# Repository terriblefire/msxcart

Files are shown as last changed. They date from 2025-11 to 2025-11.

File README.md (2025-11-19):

# MSX Cartridge - Simple CPLD-Based MegaROM Mapper

A minimalist MSX cartridge design based on the Xilinx XC9536XL CPLD, implementing a standard MegaROM mapper for bank-switched ROM cartridges.




---

## Discord

https://discord.gg/aXGkKWJQ

## ⚠️ Project Status - SUPERSEDED

**This project has been superseded by the RISKYMSX project** ([arkadiuszmakarenko/RISKYMSX](https://github.com/arkadiuszmakarenko/RISKYMSX)).

### 🎯 **We recommend building RISKYMSX instead**

RISKYMSX is a modern, feature-rich MSX cartridge solution that offers significant advantages over this simple CPLD design:

### Why Choose RISKYMSX

| Feature | RISKYMSX (Recommended) | MSX Cartridge (This Project) |
|---|---|---|
| **ROM Loading** | USB pen drive, hot-swappable | Requires ROM programmer |
| **ROM Capacity** | Up to 256KB | Up to 256KB |
| **SCC Support** | Software SCC emulation | None |
| **Convenience** | Change ROMs instantly via USB | Must reprogram ROM chip |
| **Modern MCU** | RISC-V CH32V303 | Legacy CPLD |
| **Firmware Updates** | USB or WCH-LinkE | JTAG programmer |
| **Mapper Support** | Konami, ASCII 8K/16K, Neo, SCC | Konami, ASCII 8K/16K |
| **User Experience** | Plug and play with USB drive | Requires hardware tools |

**👉 For new builds, please use [RISKYMSX](https://github.com/arkadiuszmakarenko/RISKYMSX)** - it provides better functionality, easier ROM management, and a superior user experience.

### About This Archive

This repository remains available for:
- Historical reference
- Educational purposes (learning CPLD design)
- Users who already built this hardware
- Those who need the absolute simplest possible design

However, for any new MSX cartridge project, RISKYMSX is the superior choice.

---

## Features

- **Xilinx XC9536XL CPLD** - Small, reliable, low-cost programmable logic
- **Standard MegaROM Mapper** - 4 switchable ROM pages (8KB each)
- **MSX Compatible** - Works with all MSX computers
- **Simple Design** - Minimal component count, easy to build
- **Open Source** - GPL v3 licensed hardware and HDL
- **Automated Build System** - Docker-based builds for firmware and PCB manufacturing files

## Hardware Specifications

- **Target Device**: Xilinx XC9536XL-10-VQ44 CPLD
- **Interface**: MSX cartridge slot (Z80 bus compatible)
- **Memory Mapping**: 4 page registers for bank switching
- **ROM Size**: Supports up to 512KB (limited by CPLD I/O)
- **Power**: 5V from MSX cartridge slot

## Memory Map

The mapper implements standard MSX MegaROM banking:

| Address Range | Page | Function |
|---|---|---|
| `0x4000-0x5FFF` | 0 | Fixed to bank 0 |
| `0x6000-0x7FFF` | 1 | Switchable (register 1) |
| `0x8000-0x9FFF` | 2 | Switchable (register 2) |
| `0xA000-0xBFFF` | 3 | Switchable (register 3) |

Bank switching is performed by writing to specific memory addresses during M1 cycle.

## Building

### Prerequisites

- Docker (for building firmware and PCB files)
- Git (for version control)
- Make (for build automation)

### Build Firmware

```bash
# Build CPLD firmware
make -C boards

# Output: boards/msxcart_YYYY_MM_DD_GITHASH.zip
```

### Generate PCB Manufacturing Files

```bash
# Generate Gerber files
make -C eagle gerbers

# Generate BOM and CPL for assembly
make -C eagle assembly

# Generate PDF schematic
make -C eagle pdf
```

## Manufacturing

### PCB Fabrication

1. Use the Gerber ZIP from `eagle/tfcart_*.zip` to order PCBs from your preferred manufacturer (JLCPCB, PCBWay, etc.)
2. The design is a 4-layer board optimized for standard PCB processes

### PCB Assembly

1. Use `eagle/tfcart_bom.csv` (Bill of Materials) for component ordering
2. Use `eagle/tfcart_cpl.csv` (Component Placement List) if using assembly services
3. Alternatively, hand-solder components - the board is designed for easy assembly

### Programming the CPLD

1. Connect a JTAG programmer to the CPLD
2. Flash the `.jed` file from `boards/msxcartr1/msxcartr1_top.jed`
3. Use Xilinx iMPACT or xc3sprog for programming

### Programming the ROM

1. Program your ROM chip with the desired MSX ROM image
2. Install the ROM chip in the socket
3. Insert into MSX cartridge slot

## Project Structure

```
msxcart/
├── rtl/                    # Verilog HDL source files
│   ├── msxcart_top.v      # Top-level module
│   └── mapper.v           # Memory mapper logic
├── boards/                 # CPLD build configuration
│   ├── msxcartr1/         # Revision 1 board files
│   │   ├── Makefile       # Board-specific build
│   │   └── msxcartr1.ucf  # Pin constraints
│   ├── Makefile           # Top-level build
│   ├── Makefile.inc       # Docker environment
│   └── Makefile.cpld      # Xilinx ISE flow
├── eagle/                  # PCB design files
│   ├── tfcart.brd         # Eagle board file
│   ├── tfcart.sch         # Eagle schematic
│   ├── Makefile           # PCB build automation
│   ├── extract_bom.py     # BOM extraction script
│   └── extract_cpl.py     # CPL extraction script
└── .github/workflows/      # CI/CD automation
    ├── actions.yml         # Firmware build
    ├── gerbers.yml         # Gerber generation
    ├── generate_assembly.yml # BOM/CPL generation
    ├── schematic-pdf.yml   # PDF schematic
    └── release.yml         # Release packaging
```

## Development

### Build System

The project uses Docker containers for reproducible builds:

- `terriblefire78/xilinx:v1` - Xilinx ISE 10.1 for CPLD synthesis
- `terriblefire78/eagle:v1` - Eagle CAM for Gerber generation
- `terriblefire78/eagle-pdf` - PDF schematic generation

### Modifying the Design

1. Edit Verilog files in `rtl/`
2. Adjust pin assignments in `boards/msxcartr1/msxcartr1.ucf`
3. Build and test: `make -C boards`
4. The build system automatically handles Docker environment

### Testing

Flash the generated `.jed` file to your CPLD and test with an MSX computer. The mapper should properly switch ROM banks when games access the appropriate memory addresses.

## GitHub Actions

The repository includes automated workflows:

- **Firmware Build** - Builds CPLD firmware on code changes
- **Gerber Generation** - Creates PCB manufacturing files
- **Assembly Files** - Generates BOM and CPL
- **Schematic PDF** - Produces documentation
- **Release Packaging** - Creates complete release bundles

Releases are automatically created when you push a git tag:

```bash
git tag -a v1.0 -m "Release version 1.0"
git push origin v1.0
```

## License

This project is licensed under the GNU General Public License v3.0 - see the [LICENSE](LICENSE) file for details.

Copyright (C) 2021-2025 Stephen J. Leary

## Acknowledgments

- Original design concept by Stephen J. Leary
- Inspired by the MSX community's dedication to preserving retro computing

## Related Projects

- **[RISKYMSX](https://github.com/arkadiuszmakarenko/RISKYMSX)** - Feature-rich USB-programmable MSX cartridge with SCC emulation

## Contributing

Contributions are welcome! Please feel free to submit pull requests or open issues for bugs and feature requests.

## Support

For questions, issues, or discussions:

1. Open an issue on GitHub
2. Check existing issues for solutions
3. Review the MSX community forums for related discussions

---

**Note**: This is a hardware project. Users must have appropriate skills for PCB assembly and CPLD programming. This design is provided as-is for educational and hobbyist purposes.

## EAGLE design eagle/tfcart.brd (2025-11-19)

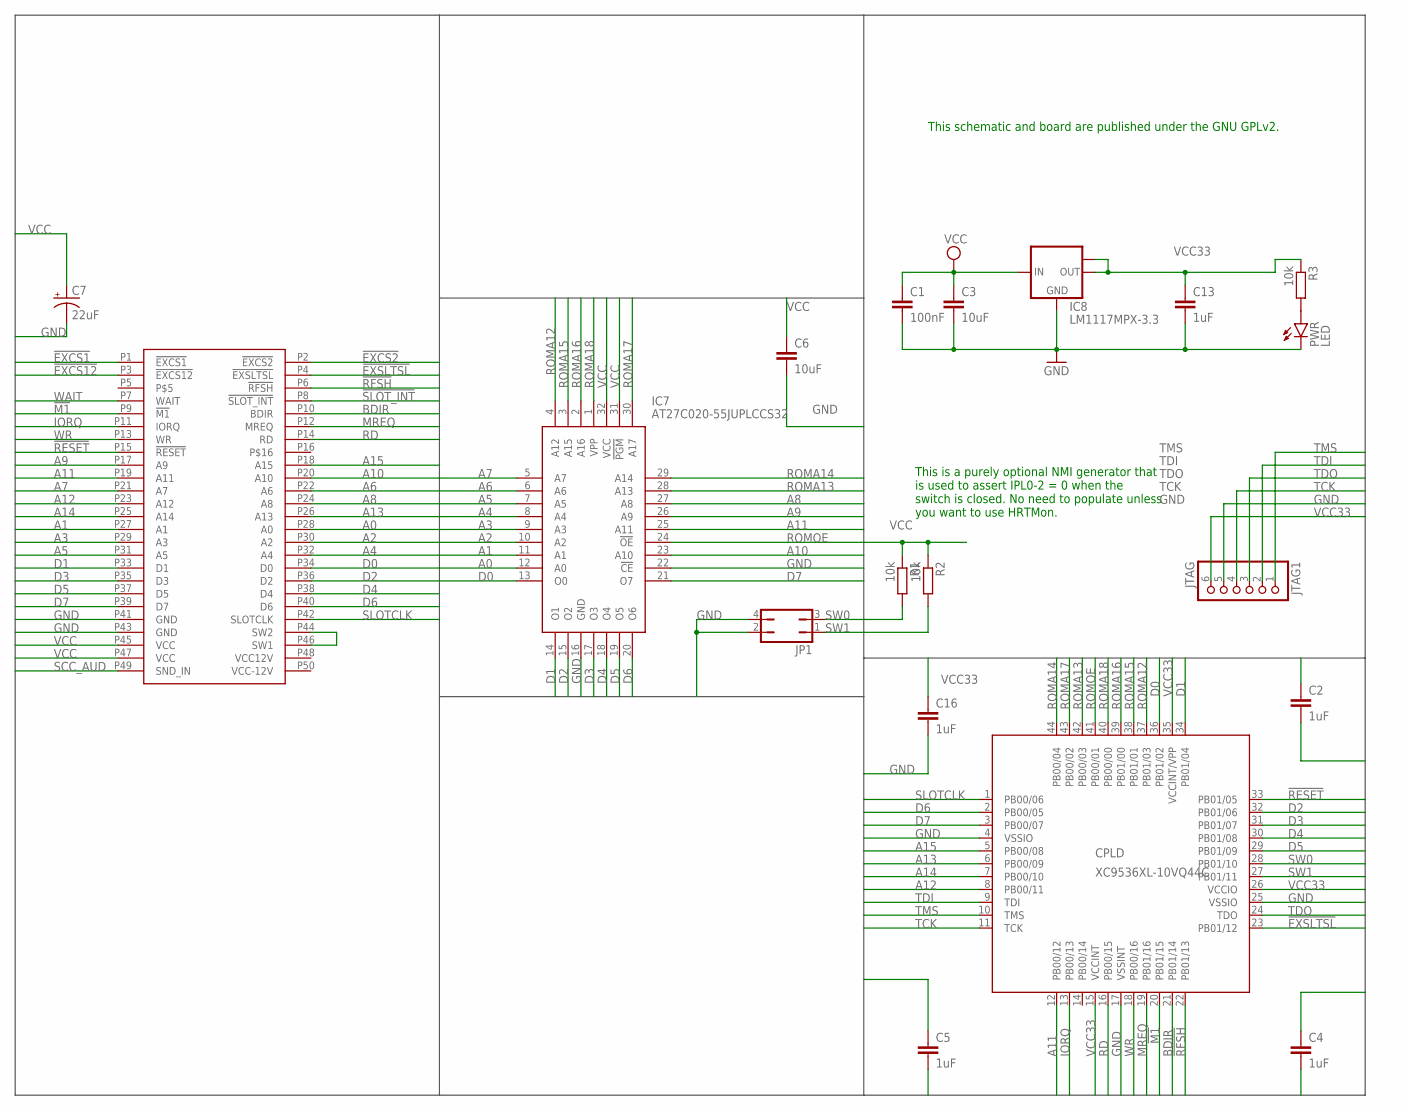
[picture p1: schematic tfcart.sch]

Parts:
C1: 100nF; C1206
C2, C4, C5, C16: 1uF; C0603
C3, C6: 10uF; C0603
C7: 22uF; PANASONIC_B
C13: 1uF; C1206
CN1: MSX_CART
CPLD: XC9536XL-10VQ44C; SQFP-S-10X10-44
IC7: AT27C020-55JUPLCCS32; PLCC-S32
IC8: LM1117MPX-3.3; SOT223
JP1: JP2Q
JTAG1: JTAG; 1X06_ROUND
PWR: LED; SML0805
R1, R2, R3: 10k; R0603

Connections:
!EXCS1: CN1.P1 (!EXCS1)
!EXCS2: CN1.P2 (!EXCS2)
!EXCS12: CN1.P3 (!EXCS12)
!EXSLTSL: CN1.P4 (!EXSLTSL), CPLD.23 (PB01/12)
!M1: CN1.P9 (!M1), CPLD.20 (PB01/15)
!RESET: CN1.P15 (!RESET), CPLD.33 (PB01/05)
!RFSH: CN1.P6 (!RFSH), CPLD.22 (PB01/13)
!SLOT_INT: CN1.P8 (!SLOT_INT)
A0: CN1.P28 (A0), IC7.12 (A0)
A1: CN1.P27 (A1), IC7.11 (A1)
A2: CN1.P30 (A2), IC7.10 (A2)
A3: CN1.P29 (A3), IC7.9 (A3)
A4: CN1.P32 (A4), IC7.8 (A4)
A5: CN1.P31 (A5), IC7.7 (A5)
A6: CN1.P22 (A6), IC7.6 (A6)
A7: CN1.P21 (A7), IC7.5 (A7)
A8: CN1.P24 (A8), IC7.27 (A8)
A9: CN1.P17 (A9), IC7.26 (A9)
A10: CN1.P20 (A10), IC7.23 (A10)
A11: CN1.P19 (A11), CPLD.12 (PB00/12), IC7.25 (A11)
A12: CN1.P23 (A12), CPLD.8 (PB00/11)
A13: CN1.P26 (A13), CPLD.6 (PB00/09)
A14: CN1.P25 (A14), CPLD.7 (PB00/10)
A15: CN1.P18 (A15), CPLD.5 (PB00/08)
BDIR: CN1.P10 (BDIR), CPLD.21 (PB01/14)
D0: CN1.P34 (D0), CPLD.36 (PB01/02), IC7.13 (O0)
D1: CN1.P33 (D1), CPLD.34 (PB01/04), IC7.14 (O1)
D2: CN1.P36 (D2), CPLD.32 (PB01/06), IC7.15 (O2)
D3: CN1.P35 (D3), CPLD.31 (PB01/07), IC7.17 (O3)
D4: CN1.P38 (D4), CPLD.30 (PB01/08), IC7.18 (O4)
D5: CN1.P37 (D5), CPLD.29 (PB01/09), IC7.19 (O5)
D6: CN1.P40 (D6), CPLD.2 (PB00/05), IC7.20 (O6)
D7: CN1.P39 (D7), CPLD.3 (PB00/07), IC7.21 (O7)
GND: C1.2, C2.2, C3.2, C4.2, C5.2, C6.2, C7.-, C13.2, C16.2, CN1.P41 (GND), CN1.P43 (GND), CPLD.4 (VSSIO), CPLD.17 (VSSINT), CPLD.25 (VSSIO), IC7.16 (GND), IC7.22 (!CE), IC8.1 (GND), JP1.2, JP1.4, JTAG1.5, PWR.C
IORQ: CN1.P11 (IORQ), CPLD.13 (PB00/13)
MREQ: CN1.P12 (MREQ), CPLD.19 (PB01/16)
unnamed: CN1.P44 (SW2), CN1.P46 (SW1)
unnamed: PWR.A, R3.2
RD: CN1.P14 (RD), CPLD.16 (PB00/15)
ROMA12: CPLD.37 (PB01/03), IC7.4 (A12)
ROMA13: CPLD.42 (PB00/03), IC7.28 (A13)
ROMA14: CPLD.44 (PB00/04), IC7.29 (A14)
ROMA15: CPLD.38 (PB01/01), IC7.3 (A15)
ROMA16: CPLD.39 (PB01/00), IC7.2 (A16)
ROMA17: CPLD.43 (PB00/02), IC7.30 (A17)
ROMA18: CPLD.40 (PB00/00), IC7.1 (VPP)
ROMOE: CPLD.41 (PB00/01), IC7.24 (!OE)
SCC_AUD: CN1.P49 (SND_IN)
SLOTCLK: CN1.P42 (SLOTCLK), CPLD.1 (PB00/06)
SW0: CPLD.28 (PB01/10), JP1.3, R1.2
SW1: CPLD.27 (PB01/11), JP1.1, R2.2
TCK: CPLD.11 (TCK), JTAG1.4
TDI: CPLD.9 (TDI), JTAG1.2
TDO: CPLD.24 (TDO), JTAG1.3
TMS: CPLD.10 (TMS), JTAG1.1
VCC: C1.1, C3.1, C6.1, C7.+, CN1.P45 (VCC), CN1.P47 (VCC), IC7.31 (!PGM), IC7.32 (VCC), IC8.3 (IN), R1.1, R2.1
VCC33: C2.1, C4.1, C5.1, C13.1, C16.1, CPLD.15 (VCCINT), CPLD.26 (VCCIO), CPLD.35 (VCCINT/VPP), IC8.2 (OUT), IC8.TAB (OUT1), JTAG1.6, R3.1
WAIT: CN1.P7 (WAIT)
WR: CN1.P13 (WR), CPLD.18 (PB00/16)

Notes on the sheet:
This is a purely optional NMI generator that is used to assert IPL0-2 = 0 when the switch is closed. No need to populate unless you want to use HRTMon.
This schematic and board are published under the GNU GPLv2.

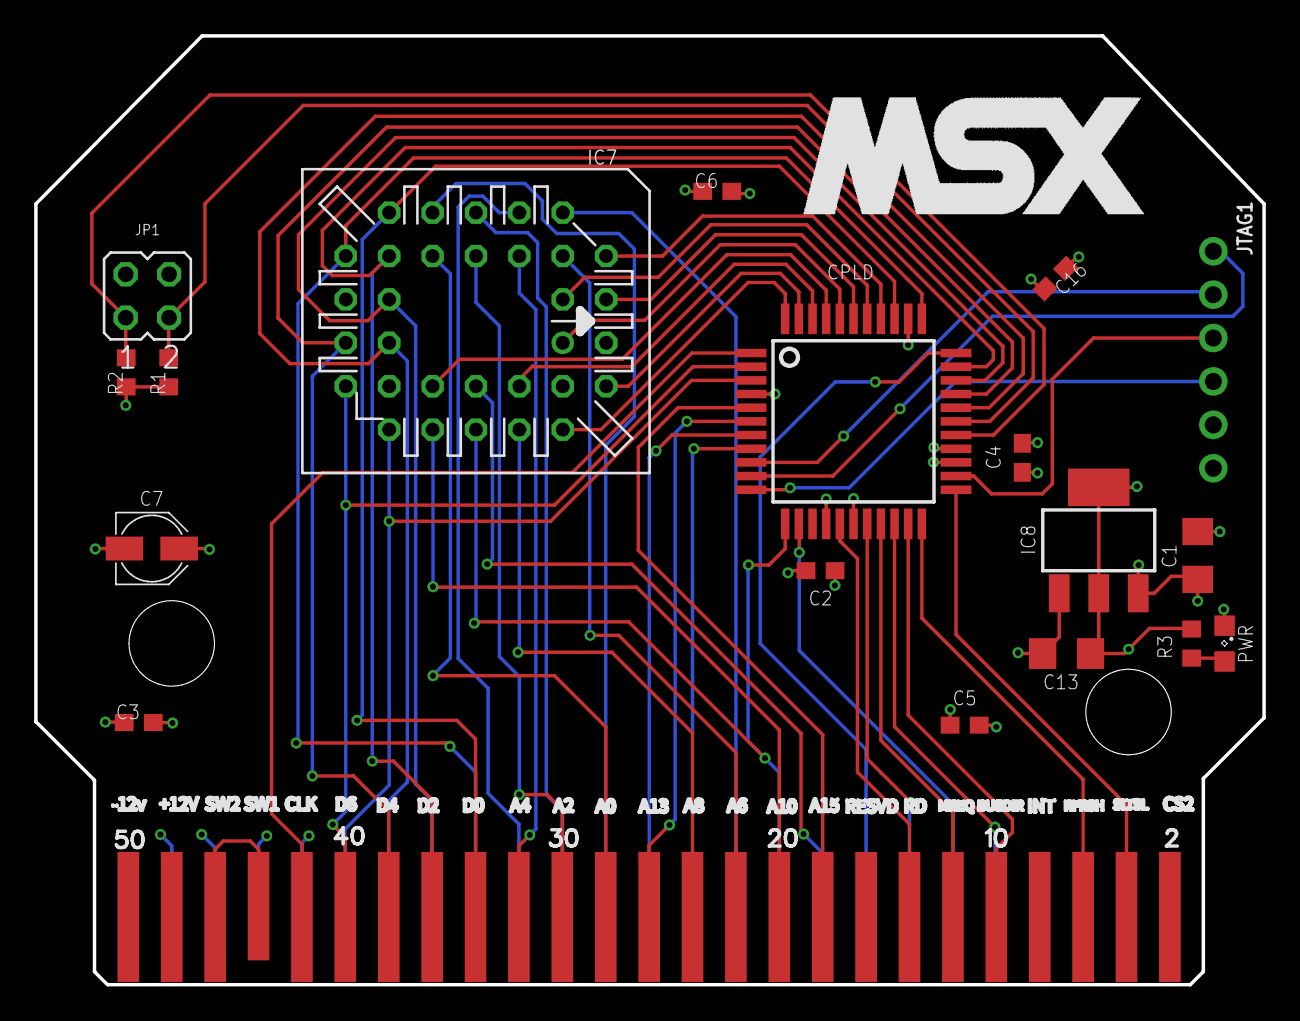
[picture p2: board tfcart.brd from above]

Board: 4 copper layers, 71.9 x 55.5 mm, 19 parts (0 on the bottom side), 53 nets.

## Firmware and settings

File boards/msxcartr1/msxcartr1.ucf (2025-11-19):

# Copyright (C) 2016-2025 Stephen J. Leary
# All rights reserved.
#
# This file is part of MSX Cartridge (msxcart)
#
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
NET "EXSLTSL"      LOC="23";
NET "M1"       LOC="20";
NET "RESET"      LOC="33";
NET "RFSH"      LOC="22";
NET "A<12>"      LOC="8";
NET "A<13>"      LOC="6";
NET "A<14>"      LOC="7";
NET "A<15>"      LOC="5";
NET "BDIR"      LOC="21";
NET "D<0>"      LOC="36";
NET "D<1>"      LOC="34";
NET "D<2>"      LOC="32";
NET "D<3>"      LOC="31";
NET "D<4>"      LOC="30";
NET "D<5>"      LOC="29";
NET "D<6>"      LOC="2";
NET "D<7>"      LOC="3";
NET "IORQ"      LOC="13";
NET "MREQ"      LOC="19";
NET "RD"      LOC="16";
NET "ROMA<12>"      LOC="37";
NET "ROMA<13>"      LOC="42";
NET "ROMA<14>"      LOC="44";
NET "ROMA<15>"      LOC="38";
NET "ROMA<16>"      LOC="39";
NET "ROMA<17>"      LOC="43";
NET "ROMA<18>"      LOC="40";
NET "ROMOE"      LOC="41";
NET "SLOTCLK"      LOC="1";
NET "SW<0>"      LOC="28";
NET "SW<1>"      LOC="27";
NET "WR"      LOC="18";

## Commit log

2023-06-24 initial commit. missing drills
    [tfcart.brd, tfcart.sch]
2025-11-19 MSX Cartridge v1.0 - Complete CPLD-based MegaROM implementation
    A minimalist MSX cartridge design based on Xilinx XC9536XL CPLD with
    complete build automation and manufacturing outputs.
    NOTE: This project has been superseded by RISKYMSX. For new builds,
    please use https://github.com/arkadiuszmakarenko/RISKYMSX which offers
    superior features including USB ROM loading, SCC emulation, and better
    user experience.
    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
    [tfcart.brd, tfcart.sch]
2025-11-19 removed redundant text from schematic
    [tfcart.sch]

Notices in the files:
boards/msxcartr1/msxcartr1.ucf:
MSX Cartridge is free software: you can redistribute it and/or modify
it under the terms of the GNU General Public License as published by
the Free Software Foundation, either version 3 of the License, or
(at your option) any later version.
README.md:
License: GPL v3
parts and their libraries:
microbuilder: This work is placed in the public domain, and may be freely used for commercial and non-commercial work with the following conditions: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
